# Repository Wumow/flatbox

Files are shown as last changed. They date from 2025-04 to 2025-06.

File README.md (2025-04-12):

# Flatbox: Low profile hitbox-layout fightstick

This repository contains 3D-printable models, PCB design files and code needed to make an arcade controller that looks like this:

Assembled Flatbox

There are nine major versions of the Flatbox. They all use Kailh low profile (choc v1) mechanical keyboard switches. The table below lists their main features. See the README for each version for details on how to make them.

version | case dimensions (mm) | compatibility | add-on board | onboard chip | SMT assembly required | firmware
------- | --------------- | ------------- | ------------ | ------------ | --------------------- | --------
[rev1.1](hardware-rev1.1) | 218x128x10 | PC, PS3 | Arduino Pro Micro | - | no | [ATmega32U4](firmware-atmega32u4)
[rev2](hardware-rev2) | 218x130x10 | PC, PS3 | - | ATmega32U4 | yes | [ATmega32U4](firmware-atmega32u4)
[rev3](hardware-rev3) | 218x130x10 | PC, PS3, PS4 or PC, Switch, PS3, PS4, PS5\* | [Brook PS3/PS4](https://www.brookaccessory.com/detail/58690501/) or [P5 mini](https://www.brookaccessory.com/detail/92299183/) | - | yes | [Brook](https://www.brookaccessory.com/download/)
[rev4.1](hardware-rev4.1) | 218x130x11 | PC, PS3, PS4\*, PS5\*, Switch | - | RP2040 | yes | [GP2040-CE](https://gp2040-ce.info/)
[rev5](hardware-rev5) | 218x126x10 | PC, PS3, PS4\*, Switch | [RP2040-Zero](https://www.waveshare.com/rp2040-zero.htm) | - | no | [GP2040-CE](https://gp2040-ce.info/)
[rev6](hardware-rev6) | 218x126x10 | PC, Switch | - | CH552T | yes | [CH552](firmware-ch552)
[rev7](hardware-rev7) | 218x130x11 | PC | [Xiao nRF52840](https://www.seeedstudio.com/Seeed-XIAO-BLE-nRF52840-p-5201.html) | - | no | [slimbox-bt](https://github.com/jfedor2/slimbox-bt)
[rev8](hardware-rev8) | 218x130x11 | PC, PS4\*, PS5\*, Switch | - | RP2350 | yes | [HID Remapper](https://github.com/jfedor2/hid-remapper)
[rev9](hardware-rev9) | 218x130x11 | PC | - | SAMD21 | yes | [CircuitPython](firmware-circuitpython)

\* - with caveats

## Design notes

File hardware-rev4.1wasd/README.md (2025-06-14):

# Flatbox rev4.1 WASD

This is rev4.1 of the Flatbox, WASD edition. In this version the PCB includes the microcontroller (RP2040) - everything is built in, you only have to add the switches (and flash the firmware). It has a USB Type A host port that you can use to plug in authentication dongles or other devices if the firmware you use supports that.

There are two variants of the case, version A uses flaps for the option buttons, version B has holes so that you can use buttoncaps on the tact switches:

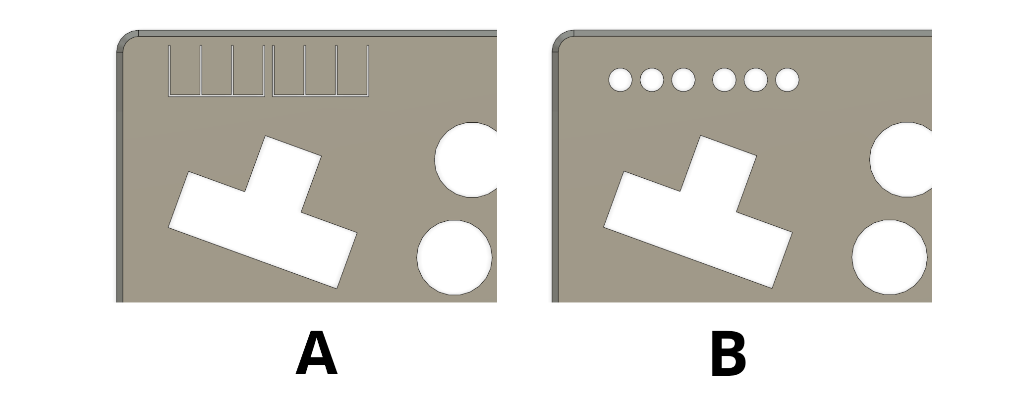
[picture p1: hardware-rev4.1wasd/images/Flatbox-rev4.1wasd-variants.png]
Flatbox rev4.1 case variants


To make one you will need:

* [3D printed](3d-printed-case) case parts - top and bottom
* [the PCB](pcb)
* 13x Kailh low profile (choc v1) switches of your choice
* (optionally) 13x Kailh low profile hotswap sockets
* buttoncaps for the action buttons, either [3D printed](../3d-printed-buttoncaps) or (preferably) injection molded (make sure they're the correct size: 22.5mm and 28.5mm)
* keycaps for the WASD section (we don't have a 3D printed version, they're widely available on AliExpress etc.)
* for case variant A:
  * 6x 6x6x5mm tact switches
* for case variant B:
  * 6x 6x6x7mm tact switches
  * 6x silicone buttoncaps (like [these](https://www.aliexpress.com/item/32846395636.html) or search for "silicone button caps" on AliExpress; or you can use other caps as long as they fit, the hole diameter is 7.5mm)
* 7x M3x6 flat head (countersunk) screws
* 5x M2x4 screws to secure the PCB to the case
* some kind of rubber feet or non-slip padding for the bottom
* a soldering iron

I printed the case at 0.20mm layer height. The top part should be printed upside-down, the bottom part should be printed as-is. They don't require supports.

I used [JLCPCB](https://jlcpcb.com/) to make the PCB and assemble the SMD parts. The [included files](pcb) can be used with JLCPCB directly. If you want to use some other service, check the file formats that they expect. When ordering from JLCPCB, upload the Gerber zip, leave all the settings at default (you can choose the PCB color), then enable "PCB Assembly" and upload the BOM and CPL files in the next step. PCB thickness should be 1.6mm.

The PCB you get from JLCPCB will look something like this:

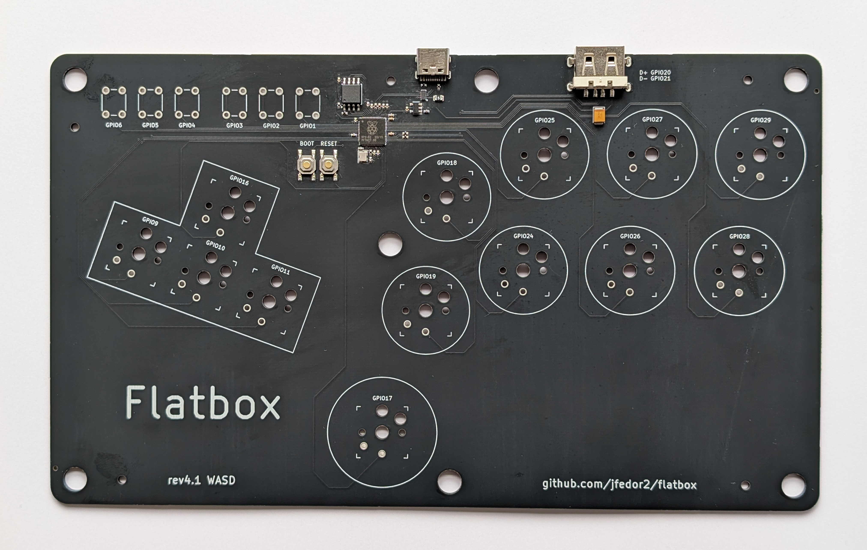
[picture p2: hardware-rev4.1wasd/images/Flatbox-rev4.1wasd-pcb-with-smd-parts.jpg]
Flatbox rev4.1 WASD PCB with SMD parts assembled


The switches can be soldered in directly to the PCB or you can use hotswap sockets.

For the firmware you probably want to use [GP2040-CE](https://gp2040-ce.info/). Go to the [GP2040-CE downloads page](https://gp2040-ce.info/downloads/) and get the UF2 file for Flatbox rev4.

To flash the firmware, connect the PCB to a computer with a USB cable, then press the RESET button while holding the BOOT button on the PCB. A drive named "RPI-RP2" should appear. Copy the UF2 file you downloaded to that drive. That's it.

You will have to configure the thumb button yourself as it has no preset function. It can be mapped separately from the WASD "up" button (it's wired to GPIO17).

(Of course you can also use any other RP2040-compatible firmware if you want.)

If you want to use the USB host port and you need to configure it in your firmware, D+ is connected to GPIO20 and D- to GPIO21.

If you want to modify the case or the PCB, check out the files in the [extras](extras) folder.

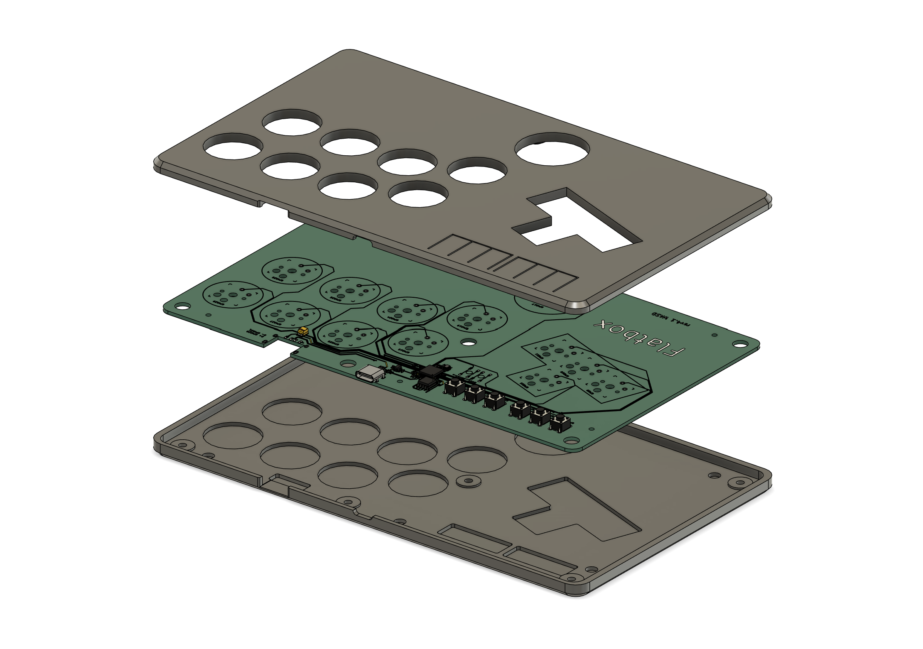
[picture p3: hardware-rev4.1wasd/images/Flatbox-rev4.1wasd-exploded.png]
Flatbox rev4.1 WASD exploded view of the 3D printed case


PCB design licensed under [CC BY-SA 4.0](https://creativecommons.org/licenses/by-sa/4.0/).

PCB design uses the following libraries:

* [keyswitches.pretty](https://github.com/daprice/keyswitches.pretty) by [daprice](https://github.com/daprice) ([CC BY-SA 4.0](https://creativecommons.org/licenses/by-sa/4.0/))
* [Type-C.pretty](https://github.com/ai03-2725/Type-C.pretty) by [ai03-2725](https://github.com/ai03-2725)
* RP2040 library from the [minimal design example](https://datasheets.raspberrypi.org/rp2040/Minimal-KiCAD.zip) from the [Hardware design with RP2040](https://datasheets.raspberrypi.org/rp2040/hardware-design-with-rp2040.pdf) document

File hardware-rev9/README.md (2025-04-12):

# Flatbox rev9

This is rev9 of the Flatbox. In this version the PCB includes the microcontroller (a SAMD21 chip) - everything is built in, you only have to add the switches (and flash the firmware).

There are two variants of the case, version A uses flaps for the option buttons, version B has holes so that you can use buttoncaps on the tact switches:

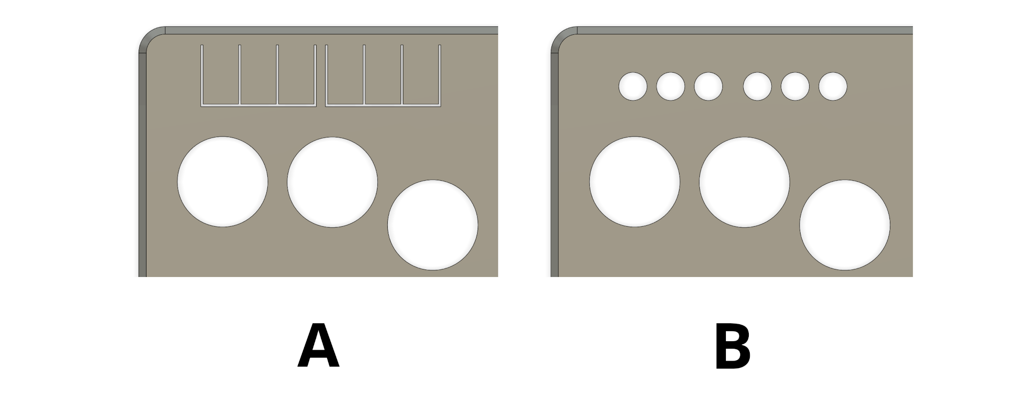
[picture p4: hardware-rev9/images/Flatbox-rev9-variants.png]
Flatbox rev9 case variants


To make one you will need:

* [3D printed case parts](3d-printed-case) - top and bottom
* [the PCB](pcb)
* 12x Kailh low profile (choc v1) switches of your choice
* (optionally) 12x Kailh low profile hotswap sockets
* buttoncaps for the action buttons, either [3D printed](../3d-printed-buttoncaps) or (preferably) injection molded (make sure they're the correct size: 22.5mm and 28.5mm)
* for case variant A:
  * 6x 6x6x5mm tact switches
* for case variant B:
  * 6x 6x6x7mm tact switches
  * 6x silicone buttoncaps (like [these](https://www.aliexpress.com/item/32846395636.html) or search for "silicone button caps" on AliExpress; or you can use other caps as long as they fit, the hole diameter is 7.5mm)
* 7x M3x6 flat head (countersunk) screws
* 5x M2x4 screws to secure the PCB to the case
* some kind of rubber feet or non-slip padding for the bottom
* a soldering iron

I printed the case at 0.20mm layer height. The top part should be printed upside-down, the bottom part should be printed as-is. They don't require supports.

I used [JLCPCB](https://jlcpcb.com/) to make the PCB and assemble the SMD parts. The [included files](pcb) can be used with JLCPCB directly. If you want to use some other service, check the file formats that they expect. When ordering from JLCPCB, upload the Gerber zip, leave all the settings at default (you can choose the PCB color), then enable "PCB Assembly" and upload the BOM and CPL files in the next step. PCB thickness should be 1.6mm.

The PCB you get from JLCPCB will look like this:

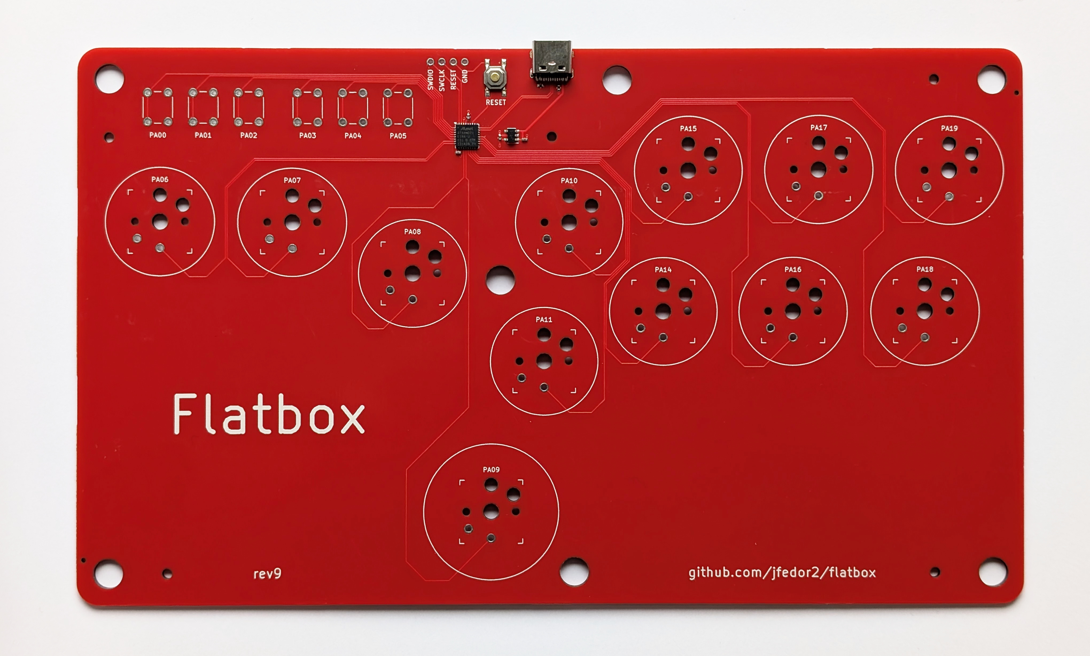
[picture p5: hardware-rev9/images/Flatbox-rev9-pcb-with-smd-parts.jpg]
Flatbox rev9 PCB with SMD parts assembled


The switches can be soldered in directly to the PCB or you can use hotswap sockets.

There are various ways that you can put firmware on the board and make it into a functional controller. Here's what I did. The relevant files are in the [binaries](binaries) folder.

1. Using an ST-Link V2 clone debug interface, put a UF2 bootloader on the board. Wire SWDIO, SWDCLK, RESET and GND lines between the ST-Link and the board and connect the board to a PC over USB for power. Then flash the bootloader with this command:<br>
`openocd -f openocd_stlink_samd21.cfg -c "init; program bootloader-flatbox_rev9-1d99238.bin verify reset; shutdown"`
2. Disconnect the ST-Link from the board.
3. Now when you connect the board to a PC, a USB drive named "FLATBOXREV9" should appear. Copy the [CircuitPython UF2](binaries/adafruit-circuitpython-flatbox_rev9-en_US-20250410-main-79e1642.uf2) file to that drive.
4. Now your board is running CircuitPython. When you connect it to a PC, a USB drive named "CIRCUITPY" should appear. Copy the files from the [firmware-circuitpython](../firmware-circuitpython) folder to that drive, then disconnect and reconnect the board. It should now show up as a game controller.

You can find the Flatbox-specific UF2 bootloader and CircuitPython modifications [here](https://github.com/jfedor2/uf2-samdx1) and [here](https://github.com/jfedor2/circuitpython). The openocd_stlink_samd21.cfg file is taken from [here](https://github.com/todbot/samd21-programming-notes).

If you ever need to get to the bootloader again to flash a different version of CircuitPython or some other UF2 file, press the RESET button twice quickly.

If you want to modify the case or the PCB, check out the files in the [extras](extras) folder.

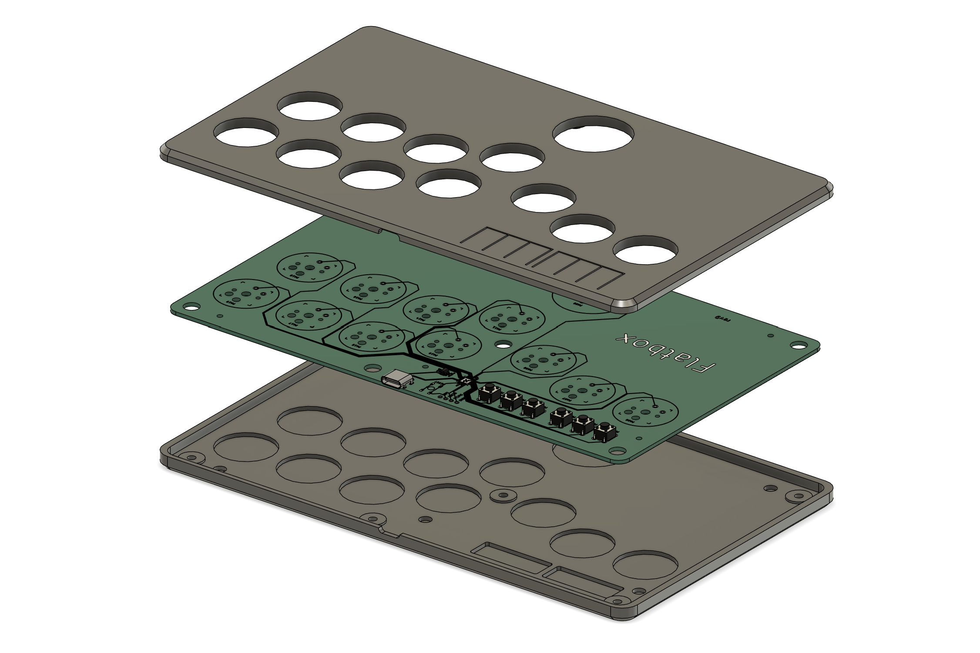
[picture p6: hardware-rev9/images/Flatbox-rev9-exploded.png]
Flatbox rev9 exploded view of the 3D printed case


PCB design licensed under [CC BY-SA 4.0](https://creativecommons.org/licenses/by-sa/4.0/).

PCB design uses the following libraries:

* [keyswitches.pretty](https://github.com/daprice/keyswitches.pretty) by [daprice](https://github.com/daprice) ([CC BY-SA 4.0](https://creativecommons.org/licenses/by-sa/4.0/))
* [Type-C.pretty](https://github.com/ai03-2725/Type-C.pretty) by [ai03-2725](https://github.com/ai03-2725)

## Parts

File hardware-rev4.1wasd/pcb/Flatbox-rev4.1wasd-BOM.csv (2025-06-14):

Value | Reference | Footprint | LCSC
100n | C1,C2,C3,C4,C5,C6,C7,C8,C9,C16 | Capacitor_SMD:C_0402_1005Metric | C1525
1u | C10,C11,C12,C13 | Capacitor_SMD:C_0402_1005Metric | C52923
15p | C14,C15 | Capacitor_SMD:C_0402_1005Metric | C1548
100u | C17 | Capacitor_Tantalum_SMD:CP_EIA-3528-21_Kemet-B | C16133
500m | F1 | Fuse:Fuse_0805_2012Metric | C2833485
27 | R1,R2 | Resistor_SMD:R_0402_1005Metric | C138021
22 | R3,R4 | Resistor_SMD:R_0402_1005Metric | C102906
1k | R5,R7 | Resistor_SMD:R_0402_1005Metric | C11702
10k | R6 | Resistor_SMD:R_0402_1005Metric | C25744
5.1k | R8,R9 | Resistor_SMD:R_0402_1005Metric | C25905
SW_Push | SW19,SW20 | SW:C318884 | C318884
RP2040 | U1 | RP2040:RP2040-QFN-56 | C2040
TLV73333PDBV | U2 | SOT-23-5:SOT-23-5 | C134139
W25Q128JVS | U3 | SOIC:SOIC-8_5.23x5.23mm_P1.27mm | C97521
~ | U4 | ECMF02-4CMX8:ECMF02-4CMX8 | C717678
HRO-TYPE-C-31-M-12 | USB1 | Type-C:HRO-TYPE-C-31-M-12-Assembly | C165948
USB_A | USB2 | Type-A:C2763302 | C2763302
Crystal_GND24 | Y1 | Crystal:Crystal_SMD_2520-4Pin_2.5x2.0mm | C90603

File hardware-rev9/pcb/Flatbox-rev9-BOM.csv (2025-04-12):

Reference | Value | Footprint | LCSC
C1,C2,C3,C4 | 1u | Capacitor_SMD:C_0402_1005Metric | C52923
R6,R7 | 5.1k | Resistor_SMD:R_0402_1005Metric | C25905
SW19 | SW_Push | SW:C318884 | C318884
U1 | ATSAMD21E18A-M | QFN32:QFN-32-1EP_5x5mm_P0.5mm_EP3.6x3.6mm_ThermalVias | C2052801
U2 | TLV73333PDBV | SOT-23-5:SOT-23-5 | C134139
USB1 | HRO-TYPE-C-31-M-12 | Type-C:HRO-TYPE-C-31-M-12-Assembly | C165948

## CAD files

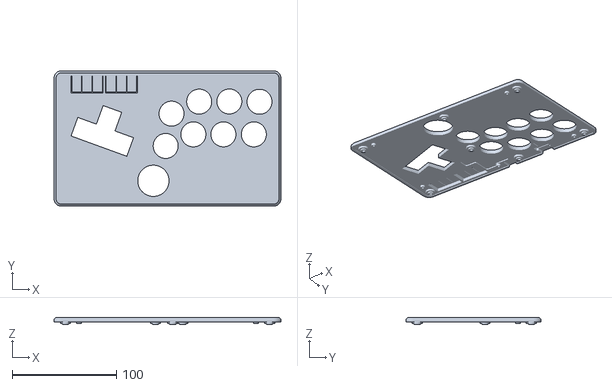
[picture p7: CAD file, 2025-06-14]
hardware-rev4.1wasd/3d-printed-case/Flatbox-rev4.1wasd-Top-A.stl
218.0 x 130.0 x 7.20

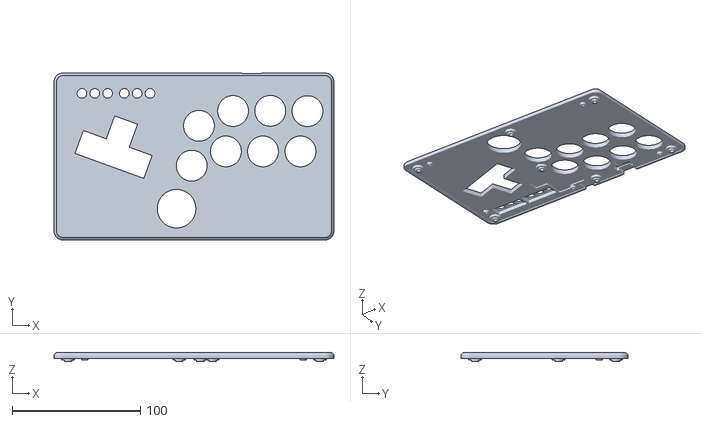
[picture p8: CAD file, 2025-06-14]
hardware-rev4.1wasd/3d-printed-case/Flatbox-rev4.1wasd-Top-B.stl
218.0 x 130.0 x 7.20

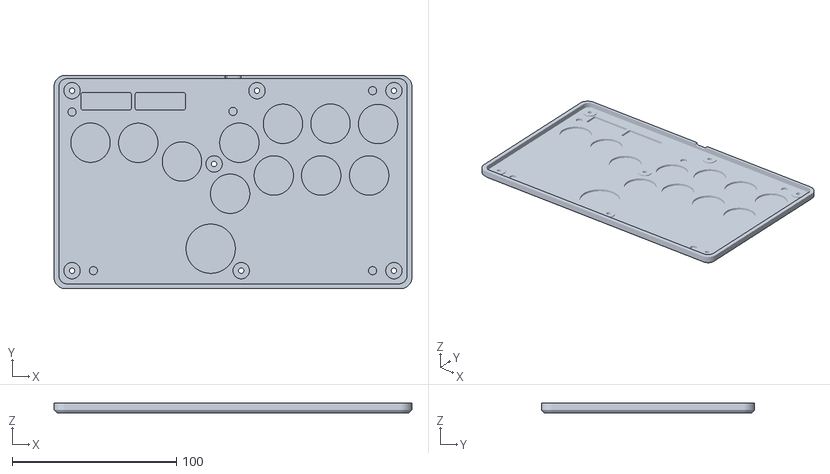
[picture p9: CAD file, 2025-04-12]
hardware-rev9/3d-printed-case/Flatbox-rev9-Bottom.stl
218.0 x 130.0 x 6.20

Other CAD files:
hardware-rev9/3d-printed-case/Flatbox-rev9-Top-A.stl
hardware-rev4.1wasd/3d-printed-case/Flatbox-rev4.1wasd-Bottom.stl
hardware-rev9/3d-printed-case/Flatbox-rev9-Top-B.stl
hardware-rev4.1/cnc-machined-case/Flatbox-rev4.1-CNC-Bottom.step
hardware-rev8/cnc-machined-case/Flatbox-rev8-CNC-Bottom.step
hardware-rev4.1/cnc-machined-case/Flatbox-rev4.1-CNC-Top.step
hardware-rev8/cnc-machined-case/Flatbox-rev8-CNC-Top.step

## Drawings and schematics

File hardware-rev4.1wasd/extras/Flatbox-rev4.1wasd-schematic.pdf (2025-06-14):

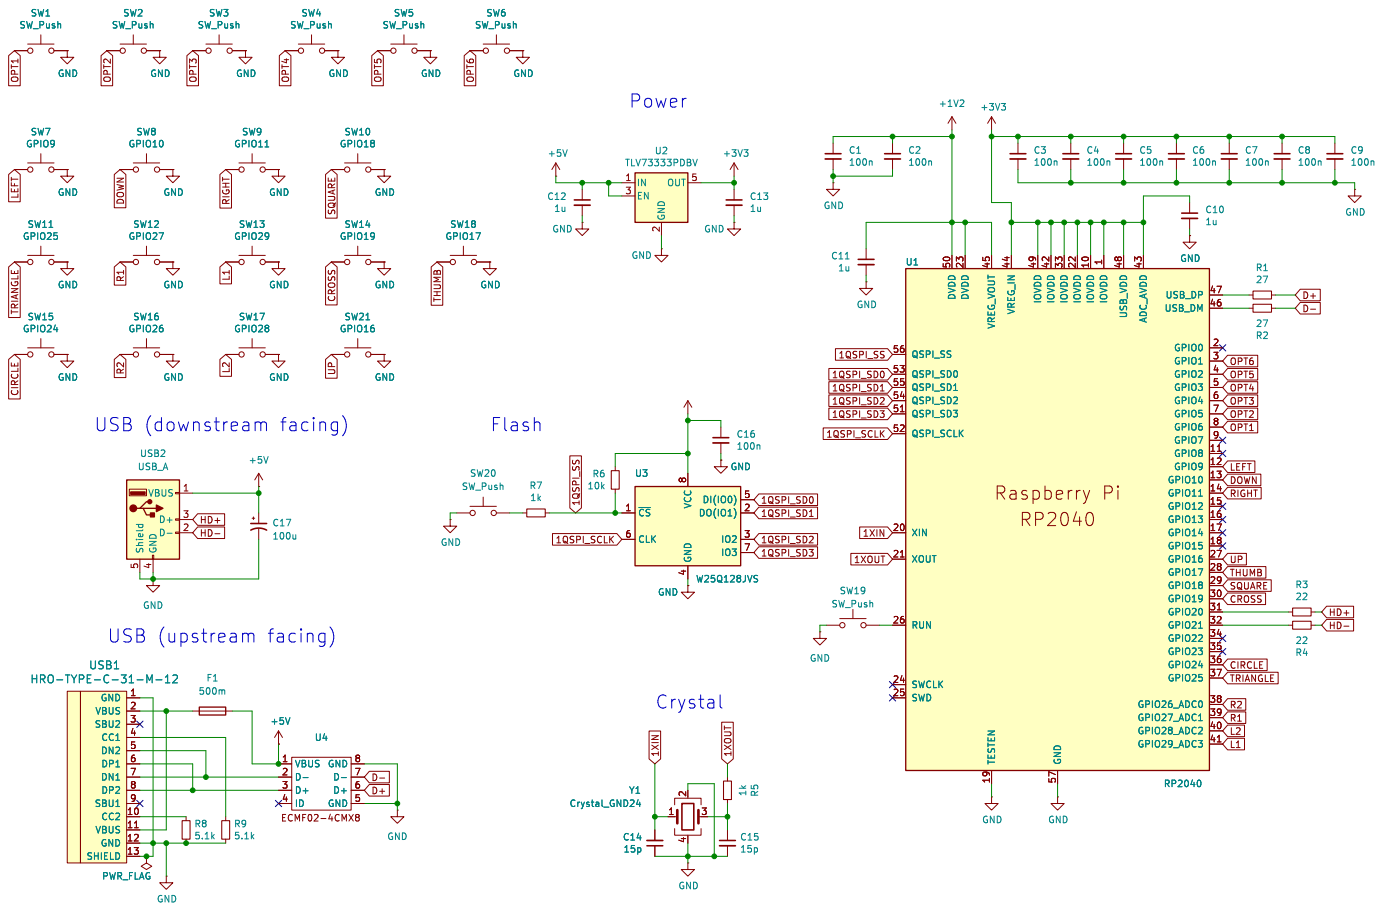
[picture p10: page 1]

1u GND 1 VBUS 2 SBU2 3 CC1 4 DN2 5 DP1 6 DN1 7 DP2 8 SBU1 9 CC2 10 VBUS 11 GND 12 SHIELD 13 USB1

HRO-TYPE-C-31-M-12 GND 1 VBUS 2 SBU2 3 CC1 4 DN2 5 DP1 6 DN1 7 DP2 8 SBU1 9 CC2 10 VBUS 11 GND 12 SHIELD 13

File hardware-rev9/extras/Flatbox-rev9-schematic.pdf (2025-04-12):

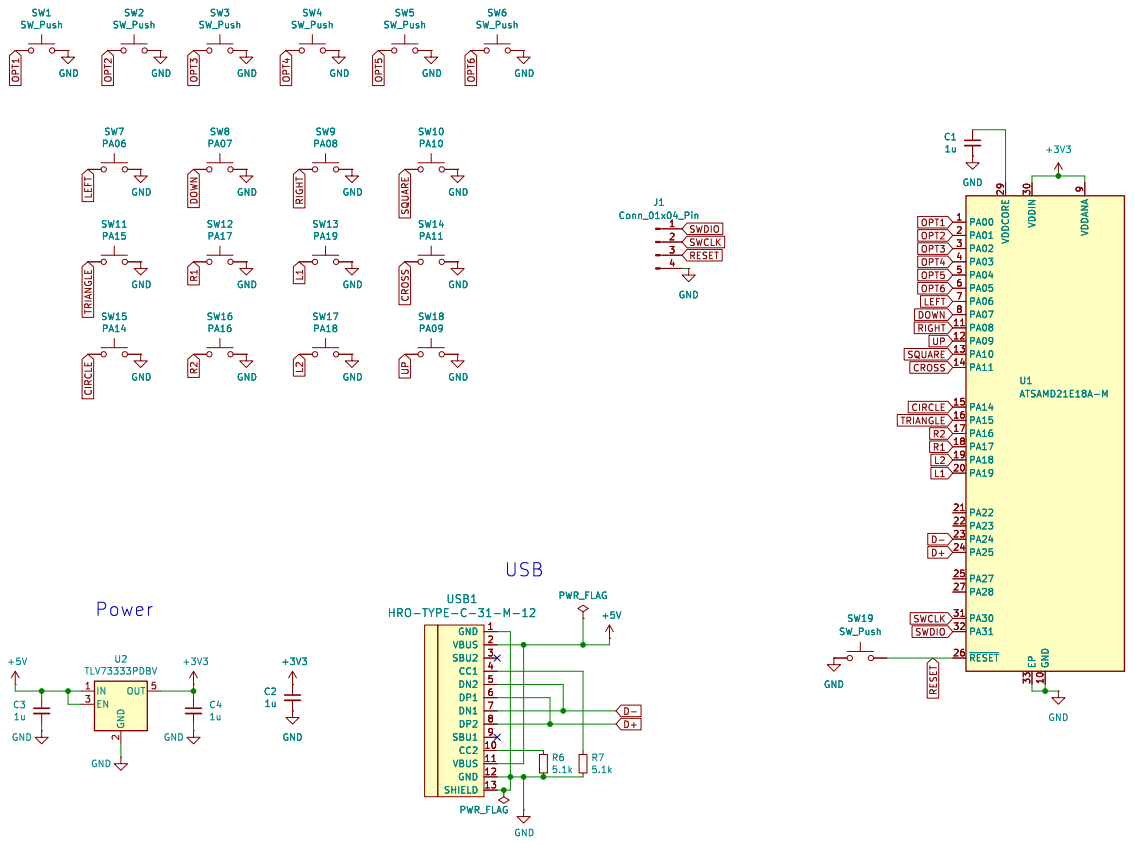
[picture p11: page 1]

LEFT CROSSUP RIGHT CIRCLE
DOWN

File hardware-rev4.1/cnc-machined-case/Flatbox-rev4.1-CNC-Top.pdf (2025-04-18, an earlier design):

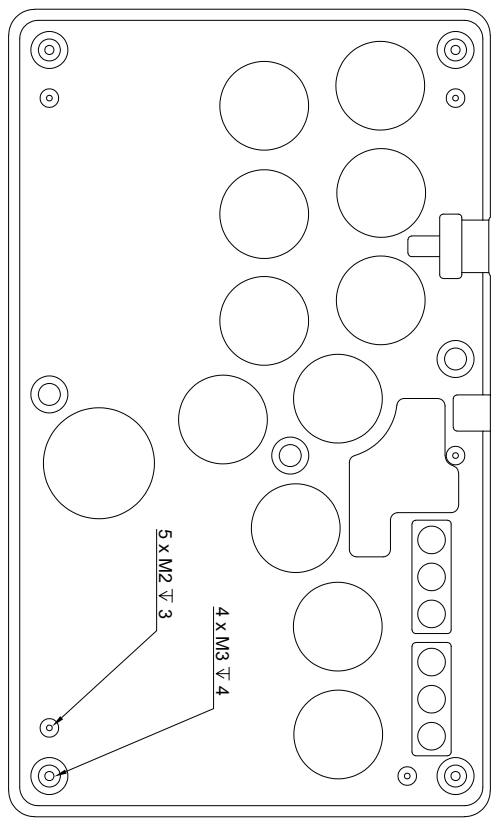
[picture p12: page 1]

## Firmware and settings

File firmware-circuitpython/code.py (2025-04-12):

import digitalio
import board
import struct
import usb_hid


def prepare_pin(p):
    pin = digitalio.DigitalInOut(p)
    pin.direction = digitalio.Direction.INPUT
    pin.pull = digitalio.Pull.UP
    return pin


dpad_pins = [prepare_pin(p) for p in [board.LEFT, board.RIGHT, board.UP, board.DOWN]]
button_pins = [
    prepare_pin(p)
    for p in [
        board.SQUARE,
        board.CROSS,
        board.CIRCLE,
        board.TRIANGLE,
        board.L1,
        board.R1,
        board.L2,
        board.R2,
        board.OPT2,
        board.OPT1,
        board.OPT5,
        board.OPT6,
        board.OPT3,
        board.OPT4,
    ]
]

dpad_lut = [
    0x0F,
    0x06,
    0x02,
    0x0F,
    0x00,
    0x07,
    0x01,
    0x00,
    0x04,
    0x05,
    0x03,
    0x04,
    0x0F,
    0x06,
    0x02,
    0x0F,
]

prev_report = None

while True:
    buttons = sum([((0 if pin.value else 1) << i) for i, pin in enumerate(button_pins)])
    dpad = dpad_lut[
        sum([((0 if pin.value else 1) << i) for i, pin in enumerate(dpad_pins)])
    ]
    report = struct.pack("<HBBBBBB", buttons, dpad, 0x80, 0x80, 0x80, 0x80, 0)
    if report != prev_report:
        usb_hid.devices[0].send_report(report)
    prev_report = report

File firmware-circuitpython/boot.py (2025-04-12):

import usb_hid

# fmt: off
report_descriptor = bytes(
    [
        0x05, 0x01,        # Usage Page (Generic Desktop Ctrls)
        0x09, 0x05,        # Usage (Game Pad)
        0xA1, 0x01,        # Collection (Application)
        0x15, 0x00,        #   Logical Minimum (0)
        0x25, 0x01,        #   Logical Maximum (1)
        0x35, 0x00,        #   Physical Minimum (0)
        0x45, 0x01,        #   Physical Maximum (1)
        0x75, 0x01,        #   Report Size (1)
        0x95, 0x0E,        #   Report Count (14)
        0x05, 0x09,        #   Usage Page (Button)
        0x19, 0x01,        #   Usage Minimum (0x01)
        0x29, 0x0E,        #   Usage Maximum (0x0E)
        0x81, 0x02,        #   Input (Data,Var,Abs,No Wrap,Linear,Preferred State,No Null Position)
        0x95, 0x02,        #   Report Count (2)
        0x81, 0x01,        #   Input (Const,Array,Abs,No Wrap,Linear,Preferred State,No Null Position)
        0x05, 0x01,        #   Usage Page (Generic Desktop Ctrls)
        0x25, 0x07,        #   Logical Maximum (7)
        0x46, 0x3B, 0x01,  #   Physical Maximum (315)
        0x75, 0x04,        #   Report Size (4)
        0x95, 0x01,        #   Report Count (1)
        0x65, 0x14,        #   Unit (System: English Rotation, Length: Centimeter)
        0x09, 0x39,        #   Usage (Hat switch)
        0x81, 0x42,        #   Input (Data,Var,Abs,No Wrap,Linear,Preferred State,Null State)
        0x65, 0x00,        #   Unit (None)
        0x95, 0x01,        #   Report Count (1)
        0x81, 0x01,        #   Input (Const,Array,Abs,No Wrap,Linear,Preferred State,No Null Position)
        0x26, 0xFF, 0x00,  #   Logical Maximum (255)
        0x46, 0xFF, 0x00,  #   Physical Maximum (255)
        0x09, 0x30,        #   Usage (X)
        0x09, 0x31,        #   Usage (Y)
        0x09, 0x32,        #   Usage (Z)
        0x09, 0x35,        #   Usage (Rz)
        0x75, 0x08,        #   Report Size (8)
        0x95, 0x04,        #   Report Count (4)
        0x81, 0x02,        #   Input (Data,Var,Abs,No Wrap,Linear,Preferred State,No Null Position)
        0x75, 0x08,        #   Report Size (8)
        0x95, 0x01,        #   Report Count (1)
        0x81, 0x01,        #   Input (Const,Array,Abs,No Wrap,Linear,Preferred State,No Null Position)
        0xC0,              # End Collection
    ]
)
# fmt: on

usb_hid.enable(
    (
        usb_hid.Device(
            report_descriptor=report_descriptor,
            usage_page=0x01,
            usage=0x05,
            report_ids=(0,),
            in_report_lengths=(8,),
            out_report_lengths=(0,),
        ),
    )
)

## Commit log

2025-04-12 Add CircuitPython firmware
2025-04-12 Add rev9
    [Flatbox-rev9-BOM.csv, Flatbox-rev9-Bottom.stl, Flatbox-rev9-Top-A.stl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]
2025-04-18 Add CNC machined case for rev4.1/rev8
    [Flatbox-rev4.1-CNC-Bottom.step, Flatbox-rev4.1-CNC-Top.step, Flatbox-rev8-CNC-Bottom.step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]
2025-06-14 Add rev4.1 WASD
    [Flatbox-rev4.1wasd-BOM.csv, Flatbox-rev4.1wasd-Bottom.stl, Flatbox-rev4.1wasd-Top-A.stl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]
